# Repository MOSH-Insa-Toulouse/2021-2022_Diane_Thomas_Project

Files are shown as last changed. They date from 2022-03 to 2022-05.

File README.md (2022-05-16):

# 2021-2022_Diane_Thomas_Project
Protocol de réalisation de capteurs low-tech à base de graphite

## Sommaire
 
  - [Test circuit avec LT-Spice](#test-circuit-avec-lt-spice)
  - [Réalisation PCB KICAD](#réalisation-pcb-kicad)
  - [Réalisation PCB physique](#réalisation-pcb-physique)
  - [Code Arduino](#code-arduino)
  - [APK MIT AppInventor](#apk-mit-appinventor)
  - [Banc de test](#banc-de-test)
  - [Amélioration à apporter](#amélioration-à-apporter)
  - [Point d'amélioration](#point-damélioration)
  - [Auteurs](#auteurs)

### Test circuit avec LT-Spice

Circuit_suggéré

Nous avons commencé par réaliser le circuit trans-impédance ci-dessus sur LT-Spice afin de déterminer la fonction de chaque filtre sur le circuit et aussi déterminer l'atténuation globale d'un bruit en courant de 50 Hz et aussi l'atténuation globale d'un bruit en courant à la fréquence limite de repliement.

1.1. Etude des filtres

Pour chaque filtre nous avons mesuré la fréquence de coupure expérimentalement avec LT-Spise et ensuite nous avons fait le calcul théorique avec la formule *fc=1/2*pi*R*C. Nous avons obtenus des valeurs expérimentales et théoriques très proches pour chaque filtre.

- Visualisation mesure filtre *R1C1*
filtre 1 R1C1

Fréquence de coupure mesurée d'environ *16Hz*, ce filtre sert à filtrer le bruit de courant et aussi d'éviter les bruits de hautes fréquences causés par distorsion dans les étages d'entrée 

- Visualisation mesures filtre *R3C4*
filtre 2 R3C4

Fréquence de coupure d'environ 1.6Hz, c'est un filtre actif passe bas qui permet d'avoir le maximum d'efficacité en maintenant le  gain constant.

- Visualition filtre R6C2
filtre 3 R6C2

 Fréquence de coupure d'environ 1.6kHz, c'est le filtre de sortie qui permet d'adapter la fréquence du signal à la carte ADC arduino. Il empêche les fréquences élevées (bruit d'alimentation...) de passer dans l'ADC
 
 - La capacité C3 elle permet de filtrer le bruit d'alimentation.
 
 1.2. Etude de l'atténuation à la fréquence de coupure et à la fréquence de niquyst
 Gain global obtenu ~140dB
 - Atténuation à la fréquence de 50Hz
 gain 50Hz
 A 50Hz on mesure un gain ~100dB ce qui traduit une atténution de ~ 40dB
 
 - Atténuation à la fréquence de niquyst=7.5kH
 gain fnyquist
 A fniquyst on a un gain de 32.8dB, ce qui traduit une atténuation de ~ 100dB

## Réalisation PCB KICAD

Pour la réalisation de notre PCB nous avons utilisé le logiciel KICAD. Nous avons d'abord effectué le schématique en assignant à chaque composants (Bluetooth, oled, encodeur rotatoire) une empreinte et un symbole que nous avons réalisé, ensuite nous avons assigné à chaque composant un motif 3D pour la visualisation, et enfin nous avons effectué le routage de notre carte PCB

2.1. Schématique

Schématique

2.2. Symbole et Empreinte des composants

-Module bluetooth

Module_bluetooth

-Encodeur rotatoire

encodeur_rotatoire

-Oled

Oled

2.3 Carte PCB 

Carte_PCB

2.4 Carte PCB visu 3d

Visu3d

## Réalisation PCB physique
Nous avons imprimé notre circuit sur une carte d'epoxy recouverte de cuivre qui est elle-même couverte par une résine positive photosensible.
Notre circuit a d'abord été imprimé(avec une imprimante classique à l'encre) sur du papier plastique transparent, faisant office de masque lors de l'insolation. 
Les motifs ont été ensuite transferrés sur la carte par insolation aux UV et un passage au développeur pour dissoudre la résine insolée.
Ensuite nous passons la carte dans un bain de perclorure de fer pour dissoudre les parties métalliques qui ont été revélées lors de l'insolation. 
Après cette étape, nous rinçons notre carte à l'eau et la plongeons dans un bain d'acétone pour enlever la résine qui protégeait les autres parties du circuit. 
Enfin l'on rince encore à l'eau et voilà, notre carte est prête. 
On utilise un foret pour le perçage et enfin on soude les composants(résistances, capacités, amplificateur,..... ) sur la carte.

CartePCB_marche

## Code Arduino 
Dans notre code arduino, nous récuperons la valeur de la tension de notre capteur que nous convertissons en résistance. Nous affichons cette tension et cette  résistance sur l'oled et sur l'application que nous avons réalisée sur MIT AppIventor en envoyant la donnée de tension par le module Bluetooth. Une pression sur l'encodeur rotatoire permet de de changer l'affichage sur l'écran OLED, et de passer de l'affichage de la résistance à l'affichage de la tension (et inversement). 

Vous trouverez le code ici [Code arduino](https://github.com/MOSH-Insa-Toulouse/2021-2022_Diane_Thomas_Project/tree/main/Code_Biblioth%C3%A8que%20Arduino/code_capteur) .

## APK MIT AppInventor
Pour Installer l'application, il vous suffit de télécharger le fichier .apk sur votre téléphone et de l'installer.
Vous trouverez ce fichier dans ce dosssier [APK app inventor](https://github.com/MOSH-Insa-Toulouse/2021-2022_Diane_Thomas_Project/tree/main/APK%20app%20inventor).
L'application permet de lire les valeurs de résistance et de tension mesurées, et aussi de voir la courbe de mesure de la résistance.
Un bouton vous permet de vous connecter et vous déconnecter. Après la mesure il est possible de récuperer les valeurs de tension et de résistance mesurées dans un fichier txt qui s'enregistre automatiquement dans vos documents.

APK

## Banc de test

Nous avons effectué notre banc de test en utilisant des cylindres de différents diamètres(1, 1.5, 2, 2.5, 3, 3.5, 4 cm) fabriqués avec du papier recyclé. On met le capteur en tension, en le faisant épouser la forme des différents cylindre).
Les resultats peuvent être consulté ici [Datasheet et banc de test](https://github.com/MOSH-Insa-Toulouse/2021-2022_Diane_Thomas_Project/tree/main/Datasheet%20et%20banc%20de%20test) .

Cylindre_banc_test

## Amélioration à apporter
Notre banc de test présente certaines limites et peut être amélioré.
On a:

- La non répétabilité des mesures. En effet, les déformations appliquées peuvent varier entre chaque mesure: le banc de test ne permet pas d’appliquer une déformation identique. On pourrait envisager un banc de test fonctionnant avec un servomoteur par exemple (Ce système permet de générer des contraintes avec des angles bien précis et d'obtenir, de ce fait, une meilleure reproductibilité)

- Le dépôt de graphite sur le papier qui ne peut pas être maitrisé cela conduit une variation de mesure pour différents dépôts de même graphite.

-la déformation irréversible du capteur après un certains nombres de mesures.

#### Point d'amélioration

Afin de pouvoir lire une plus grande plage de résistance tout en ayant des mesures stables, il faudrait pouvoir changer le gain du circuit trans-impédance c'est à dire modifier la résistance R2 (voir schéma KiCad ). Cependant nous l'avons soudée sur le circuit PCB. Il faut donc à la place de la résistance R2 mettre un potentiomètre qui permet de varier  celle-ci.

## Auteurs
  
  - Bonkoungou Diane bonkoung@etud.insa-toulouse.fr
  - Bousquet Thomas tbousque@etud.insa-toulouse.fr

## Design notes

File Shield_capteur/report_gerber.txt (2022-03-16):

Plotted to 'C:\Users\diane\Desktop\GIT_Depot\MOSCH_project\2021-2022_Diane_Thomas_Project\Shiel_capteur\Fichier Gerber\LT1050-B_Cu.pdf'.
Info: Fini.

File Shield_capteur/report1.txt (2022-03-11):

Info: Processing symbol 'C1:Capacitor_THT:C_Disc_D10.0mm_W2.5mm_P5.00mm'.
Info: Processing symbol 'P7:Socket_Arduino_Uno:Arduino_1pin'.
Info: Processing symbol 'P8:Socket_Arduino_Uno:Arduino_1pin'.
Info: Processing symbol 'C2:Capacitor_THT:C_Disc_D10.0mm_W2.5mm_P5.00mm'.
Info: Processing symbol 'C3:Capacitor_THT:C_Disc_D10.0mm_W2.5mm_P5.00mm'.
Info: Processing symbol 'C4:Capacitor_THT:C_Rect_L9.0mm_W5.1mm_P7.50mm_MKT'.
Info: Processing symbol 'R1:Resistor_THT:R_Axial_DIN0207_L6.3mm_D2.5mm_P10.16mm_Horizontal'.
Info: Processing symbol 'R3:Resistor_THT:R_Axial_DIN0207_L6.3mm_D2.5mm_P10.16mm_Horizontal'.
Info: Processing symbol 'keyes_KY_1:Librarie_composant:Encodeur_rotatoire'.
Info: Processing symbol 'R2:Resistor_THT:R_Axial_DIN0207_L6.3mm_D2.5mm_P10.16mm_Horizontal'.
Info: Processing symbol 'P3:Socket_Arduino_Uno:Socket_Strip_Arduino_1x10'.
Info: Processing symbol 'U3:Librarie_composant:Module bluetooth'.
Info: Processing symbol 'R5:Resistor_THT:R_Axial_DIN0207_L6.3mm_D2.5mm_P10.16mm_Horizontal'.
Info: Processing symbol 'P5:Socket_Arduino_Uno:Arduino_1pin'.
Info: Processing symbol 'P4:Socket_Arduino_Uno:Socket_Strip_Arduino_1x08'.
Info: Processing symbol 'P6:Socket_Arduino_Uno:Arduino_1pin'.
Info: Processing symbol 'P1:Socket_Arduino_Uno:Socket_Strip_Arduino_1x08'.
Info: Processing symbol 'P2:Socket_Arduino_Uno:Socket_Strip_Arduino_1x06'.
Info: Processing symbol 'R6:Resistor_THT:R_Axial_DIN0207_L6.3mm_D2.5mm_P10.16mm_Horizontal'.
Info: Processing symbol 'U1:Librarie_composant:DIP-8_296_ELL'.
Info: Processing symbol 'U2:Librarie_composant:Capteur_graphite'.
Info: Processing symbol 'U4:Librarie_composant:OLED'.
Add net CLK.
Reconnected keyes_KY_1 pin 1 from unconnected-(keyes_KY_1-Pad1) to CLK.
Reconnected keyes_KY_1 pin 2 from unconnected-(keyes_KY_1-Pad2) to DT.
Add net SW.
Reconnected keyes_KY_1 pin 3 from unconnected-(keyes_KY_1-Pad3) to SW.
Reconnected keyes_KY_1 pin 4 from unconnected-(keyes_KY_1-Pad4) to +5V.
Reconnected P2 pin 1 from /A0 to ADC.
Add net SDA.
Reconnected P2 pin 5 from /A4(SDA) to SDA.
Add net SCL.
Reconnected P2 pin 6 from /A5(SCL) to SCL.
Reconnected P3 pin 7 from /11(**/MOSI) to SW.
Reconnected P3 pin 8 from /10(**/SS) to DT.
Add net /7.
Reconnected P4 pin 1 from +5V to /7.
Reconnected P4 pin 6 from 2 to CLK.
Add net TXD.
Reconnected P4 pin 7 from /1(Tx) to TXD.
Add net RXD.
Reconnected P4 pin 8 from /0(Rx) to RXD.
Reconnected R1 pin 1 from 3 to IN+.
Reconnected R2 pin 2 from 2 to IN-.
Reconnected R3 pin 1 from 2 to IN-.
Add net DT.
Reconnected R5 pin 1 from /Isens to capteur.
Reconnected R5 pin 2 from 3 to IN+.
Add net IN+.
Reconnected C1 pin 1 from 3 to IN+.
Reconnected U1 pin 2 from 2 to IN-.
Reconnected U1 pin 3 from 3 to IN+.
Add net IN-.
Updated U2 symbol association from /3deabf90-4200-44e5-96f0-6dbdb285e2f9 to /9f589ed3-a6b9-4e31-a518-6362035b54b5.
Connected U2 pin 1 to capteur.
Connected U2 pin 2 to +5V.
Add net capteur.
Added U3 (footprint 'Librarie_composant:Module bluetooth').
Changed HC-05 reference designator to U3.
Changed U3 value from Module bluetooth to Module_bluetooth.
Updated U3 symbol association from  to /ebefff93-806b-4ffd-bb33-46db61c698c7.
Updated U3 properties.
Add net unconnected-(U3-Pad1).
Connected U3 pin 1 to unconnected-(U3-Pad1).
Connected U3 pin 2 to +5V.
Connected U3 pin 3 to GND.
Connected U3 pin 4 to TXD.
Connected U3 pin 5 to RXD.
Add net unconnected-(U3-Pad6).
Connected U3 pin 6 to unconnected-(U3-Pad6).
Reconnected C4 pin 1 from 2 to IN-.
Added U4 (footprint 'Librarie_composant:OLED').
Changed REF** reference designator to U4.
Updated U4 symbol association from  to /e9f552ce-c538-4f28-af5f-c07fb8584760.
Updated U4 properties.
Connected U4 pin 1 to +5V.
Connected U4 pin 2 to GND.
Connected U4 pin 3 to SCL.
Connected U4 pin 4 to SDA.
Removed unused net /0(Rx).
Removed unused net /1(Tx).
Removed unused net /10(**{slash}SS).
Removed unused net /11(**{slash}MOSI).
Removed unused net /A0.
Removed unused net /Isens.
Removed unused net 2.
Removed unused net 3.
Removed unused net unconnected-(keyes_KY_1-Pad1).
Removed unused net unconnected-(keyes_KY_1-Pad2).
Removed unused net unconnected-(keyes_KY_1-Pad3).
Removed unused net unconnected-(keyes_KY_1-Pad4).

Info: Total warnings: 0, errors: 0.

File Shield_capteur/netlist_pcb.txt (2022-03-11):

Info: Reading netlist file 'C:\Users\diane\Desktop\Shield arduino\PCB_EXAM\LT1050\netlist.net'.

Info: Using reference designators to match symbols and footprints.

Info: Processing symbol 'P3:Socket_Arduino_Uno:Socket_Strip_Arduino_1x10'.
Info: Processing symbol 'P1:Socket_Arduino_Uno:Socket_Strip_Arduino_1x08'.
Info: Processing symbol 'P4:Socket_Arduino_Uno:Socket_Strip_Arduino_1x08'.
Info: Processing symbol 'P2:Socket_Arduino_Uno:Socket_Strip_Arduino_1x06'.
Info: Processing symbol 'P5:Socket_Arduino_Uno:Arduino_1pin'.
Info: Processing symbol 'P6:Socket_Arduino_Uno:Arduino_1pin'.
Info: Processing symbol 'P7:Socket_Arduino_Uno:Arduino_1pin'.
Info: Processing symbol 'P8:Socket_Arduino_Uno:Arduino_1pin'.
Info: Processing symbol 'U1:Librarie_composant:DIP-8_296_ELL'.

Info: Total warnings: 0, errors: 0.

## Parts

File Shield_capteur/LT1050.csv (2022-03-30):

Source: | C:\Users\diane\Desktop\GIT_Depot\MOSCH_project\2021-2022_Diane_Thomas_Project\Shiel_capteur\LT1050.kicad_sch
Date: | 16/03/2022 17:25:07
Tool: | Eeschema (6.0.1)
Generator: | C:\Program Files\KiCad\6.0\bin\scripting\plugins/bom_csv_grouped_by_value_with_fp.py
Component Count: | 22
Ref | Qnty | Value | Cmp name | Footprint | Description | Vendor
C1, C2, C3, | 3 | 100n | C | Capacitor_THT:C_Disc_D3.4mm_W2.1mm_P2.50mm | Unpolarized capacitor
C4, | 1 | 1u | C | Capacitor_THT:C_Rect_L9.0mm_W5.1mm_P7.50mm_MKT | Unpolarized capacitor
keyes_KY_1, | 1 | Encodeur_rotatoire | Encodeur_rotatoire | Librarie_composant:Encodeur_rotatoire
P1, | 1 | Power | Conn_01x08 | Socket_Arduino_Uno:Socket_Strip_Arduino_1x08 | Generic connector, single row, 01x08, script generated (kicad-library-utils/schlib/autogen/connector/)
P2, | 1 | Analog | Conn_01x06 | Socket_Arduino_Uno:Socket_Strip_Arduino_1x06 | Generic connector, single row, 01x06, script generated (kicad-library-utils/schlib/autogen/connector/)
P3, | 1 | Digital | Conn_01x10 | Socket_Arduino_Uno:Socket_Strip_Arduino_1x10 | Generic connector, single row, 01x10, script generated (kicad-library-utils/schlib/autogen/connector/)
P4, | 1 | Digital | Conn_01x08 | Socket_Arduino_Uno:Socket_Strip_Arduino_1x08 | Generic connector, single row, 01x08, script generated (kicad-library-utils/schlib/autogen/connector/)
P5, P6, P7, P8, | 4 | CONN_01X01 | Conn_01x01 | Socket_Arduino_Uno:Arduino_1pin | Generic connector, single row, 01x01, script generated (kicad-library-utils/schlib/autogen/connector/)
R1, R3, | 2 | 100k | R | Resistor_THT:R_Axial_DIN0207_L6.3mm_D2.5mm_P10.16mm_Horizontal | Resistor
R2, R6, | 2 | 1k | R | Resistor_THT:R_Axial_DIN0207_L6.3mm_D2.5mm_P10.16mm_Horizontal | Resistor
R5, | 1 | 10k | R | Resistor_THT:R_Axial_DIN0207_L6.3mm_D2.5mm_P10.16mm_Horizontal | Resistor
U0, | 1 | Capteur_graphite | Capteur_graphite_1 | Librarie_composant:Capteur_graphite
U1, | 1 | LT1050 | LT1050 | Librarie_composant:DIP-8_296_ELL
U2, | 1 | Module_bluetooth | Module_bluetooth_1 | Librarie_composant:Module bluetooth
U3, | 1 | OLED | OLED | Librarie_composant:OLED

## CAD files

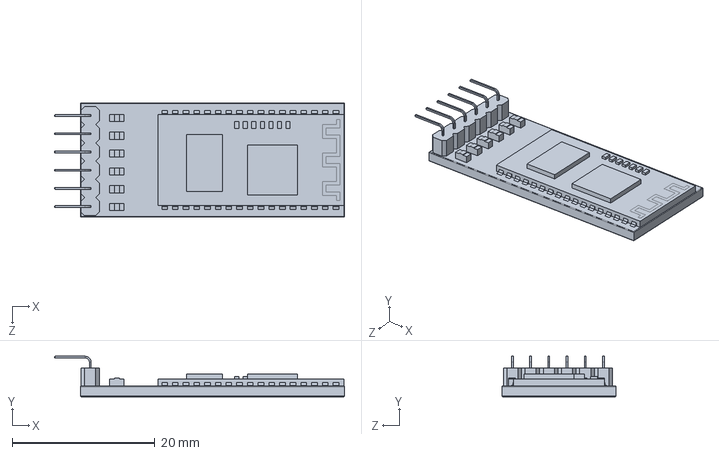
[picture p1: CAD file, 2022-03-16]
Shield_capteur/Motif 3d/HC05.STEP
40.6 x 5.67 x 16.0 mm

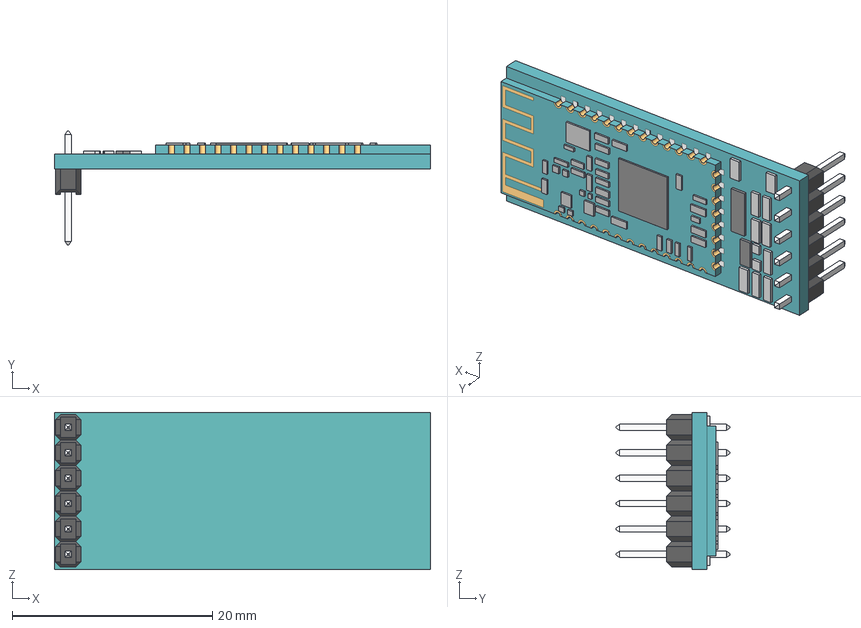
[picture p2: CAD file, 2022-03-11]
Shield_capteur/Motif 3d/HC-SERIES.STEP
37.6 x 11.4 x 15.7 mm
Pin Header 6 x 1 TH 2.54mm Pitch x 12

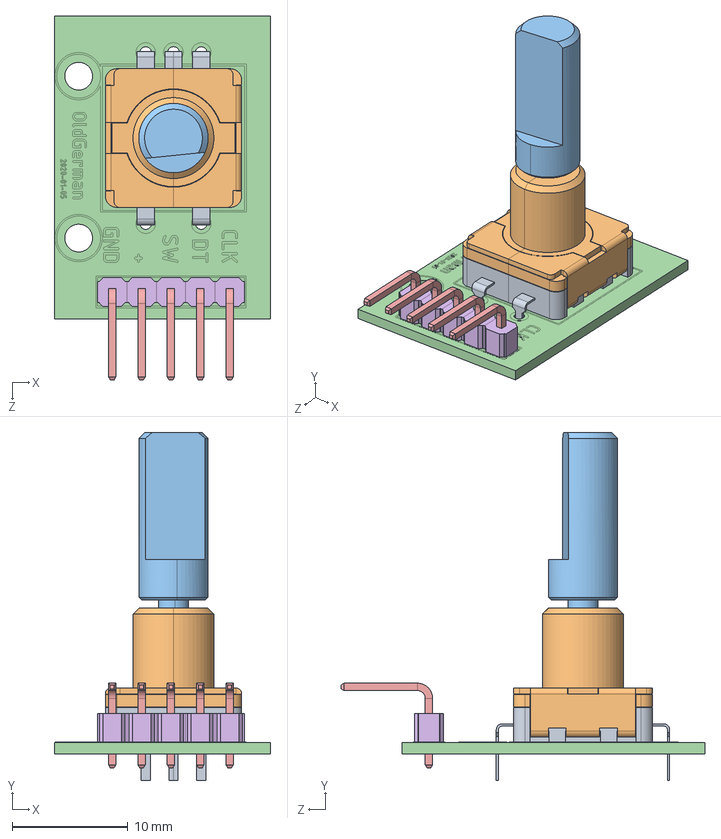
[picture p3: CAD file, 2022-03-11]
Shield_capteur/Motif 3d/KY-040 Rotary Encoder.STEP
18.7 x 30.1 x 31.5 mm
Rotary Encoder
D-handle
pcb
2.54 5PIN 90

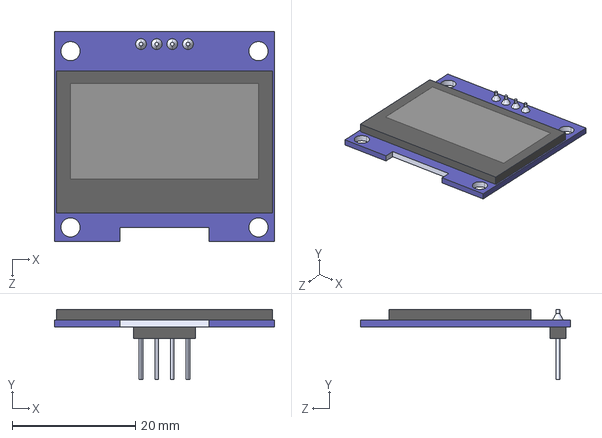
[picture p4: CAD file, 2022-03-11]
Shield_capteur/Motif 3d/Display_OLED_SSD1306_1.3inch.STEP
35.7 x 11.4 x 34.0 mm

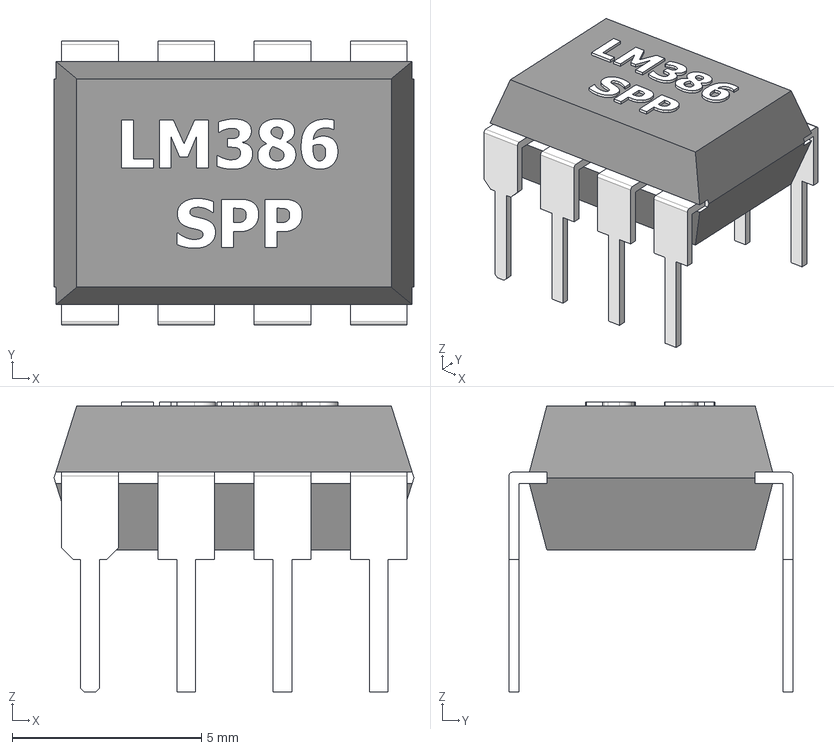
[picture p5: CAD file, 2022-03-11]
Shield_capteur/Motif 3d/LM386 SPP.stp
9.50 x 7.50 x 7.65 mm

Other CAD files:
Shield_capteur/Motif 3d/HC_05 Blue Tooth Module.ipt

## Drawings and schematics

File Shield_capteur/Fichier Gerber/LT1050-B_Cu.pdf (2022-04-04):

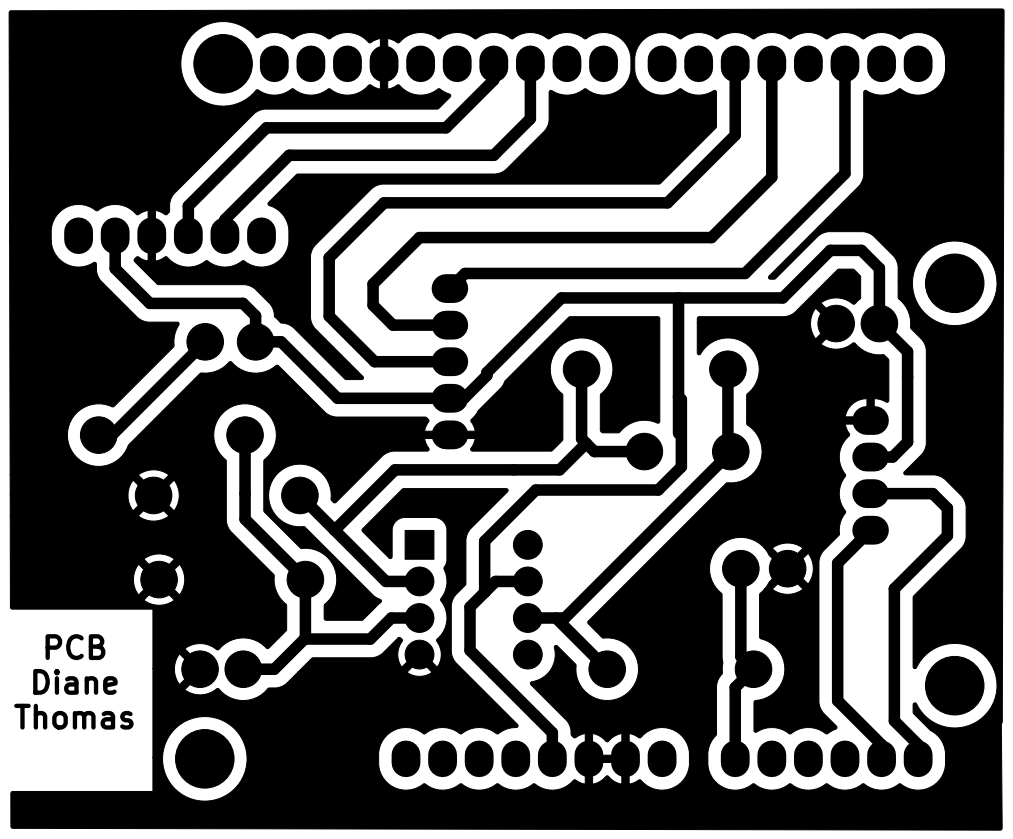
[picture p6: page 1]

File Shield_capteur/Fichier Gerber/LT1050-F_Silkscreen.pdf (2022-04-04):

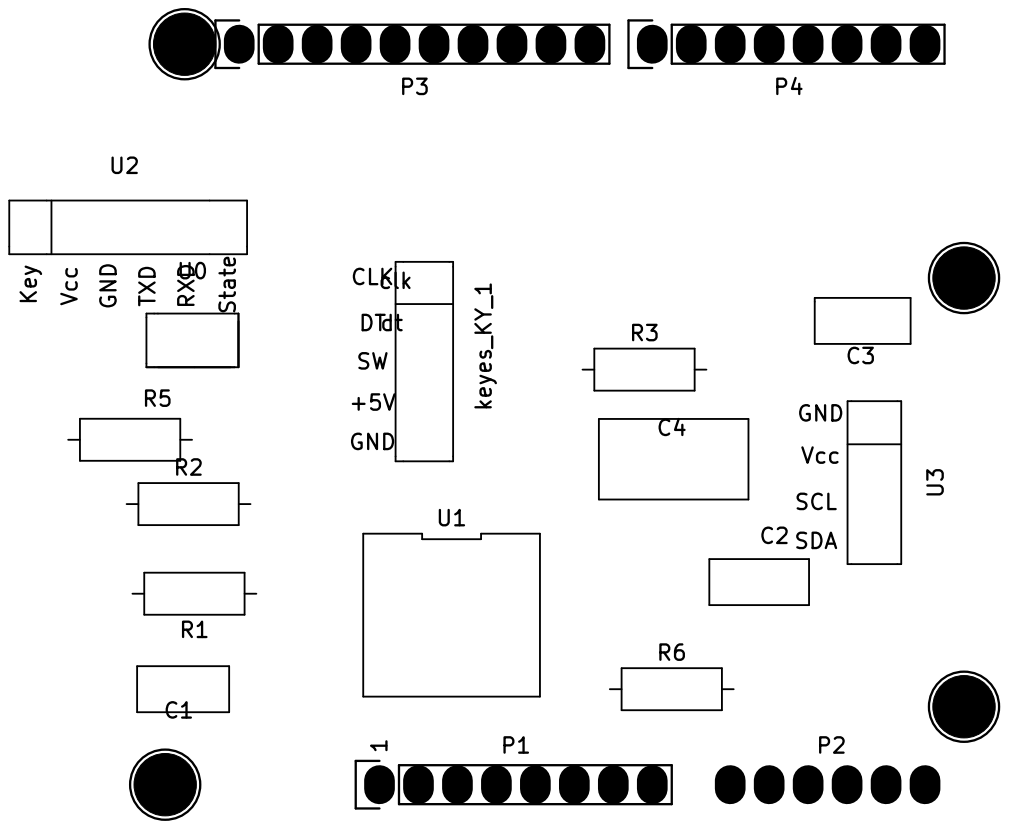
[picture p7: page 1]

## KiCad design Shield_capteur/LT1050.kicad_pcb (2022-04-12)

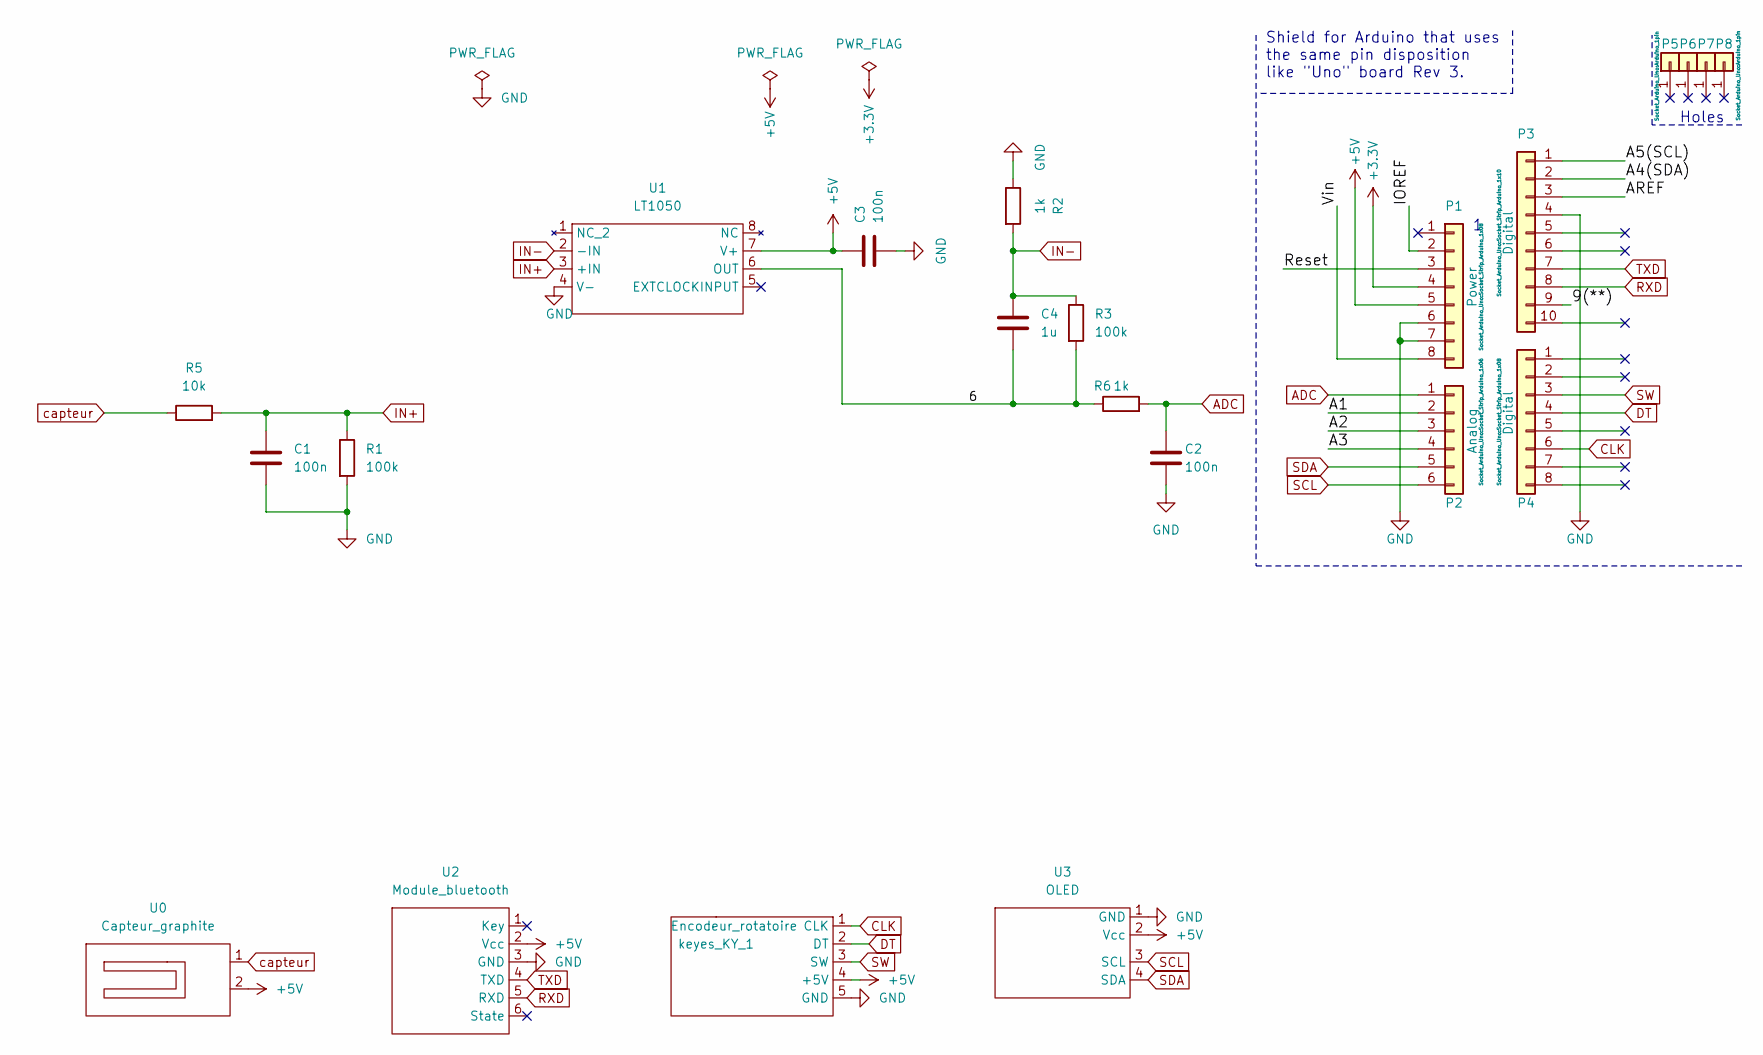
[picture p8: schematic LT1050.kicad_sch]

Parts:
C1, C2, C3: 100n; C_Disc_D3.4mm_W2.1mm_P2.50mm
C4: 1u; C_Rect_L7.5mm_W6.5mm_P5.00mm
P1: Power; Socket_Strip_Arduino_1x08
P2: Analog; Socket_Strip_Arduino_1x06
P3: Digital; Socket_Strip_Arduino_1x10
P4: Digital; Socket_Strip_Arduino_1x08
P5, P6, P7, P8: CONN_01X01; Arduino_1pin
R1, R3: 100k; R_Axial_DIN0207_L6.3mm_D2.5mm_P10.16mm_Horizontal
R2, R6: 1k; R_Axial_DIN0207_L6.3mm_D2.5mm_P10.16mm_Horizontal
R5: 10k; R_Axial_DIN0207_L6.3mm_D2.5mm_P10.16mm_Horizontal
U0: Capteur_graphite
U1: LT1050; DIP-8_296_ELL
U2: Module_bluetooth; Module bluetooth
U3: OLED
keyes_KY_1: Encodeur_rotatoire

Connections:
+3V3: P1.4
+5V: C3.1, P1.5, U0.2, U1.7 (V+), U2.2 (Vcc), U3.2 (Vcc), keyes_KY_1.4 (+5V)
/6: C4.2, R3.2, R6.1, U1.6 (OUT)
/9(**): P3.9
/A1: P2.2
/A2: P2.3
/A3: P2.4
/A4(SDA): P3.2
/A5(SCL): P3.1
/AREF: P3.3
/IOREF: P1.2
/Reset: P1.3
/Vin: P1.8
ADC: C2.1, P2.1, R6.2
CLK: P4.6, keyes_KY_1.1 (CLK)
DT: P4.4, keyes_KY_1.2 (DT)
GND: C1.2, C2.2, C3.2, P1.6, P1.7, P3.4, R1.2, R2.1, U1.4 (V-), U2.3 (GND), U3.1 (GND), keyes_KY_1.5 (GND)
IN+: C1.1, R1.1, R5.2, U1.3 (+IN)
IN-: C4.1, R2.2, R3.1, U1.2 (-IN)
RXD: P3.8, U2.5 (RXD)
SCL: P2.6, U3.3 (SCL)
SDA: P2.5, U3.4 (SDA)
SW: P4.3, keyes_KY_1.3 (SW)
TXD: P3.7, U2.4 (TXD)
capteur: R5.1, U0.1

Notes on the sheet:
Holes
Shield for Arduino that uses the same pin disposition like "Uno" board Rev 3.

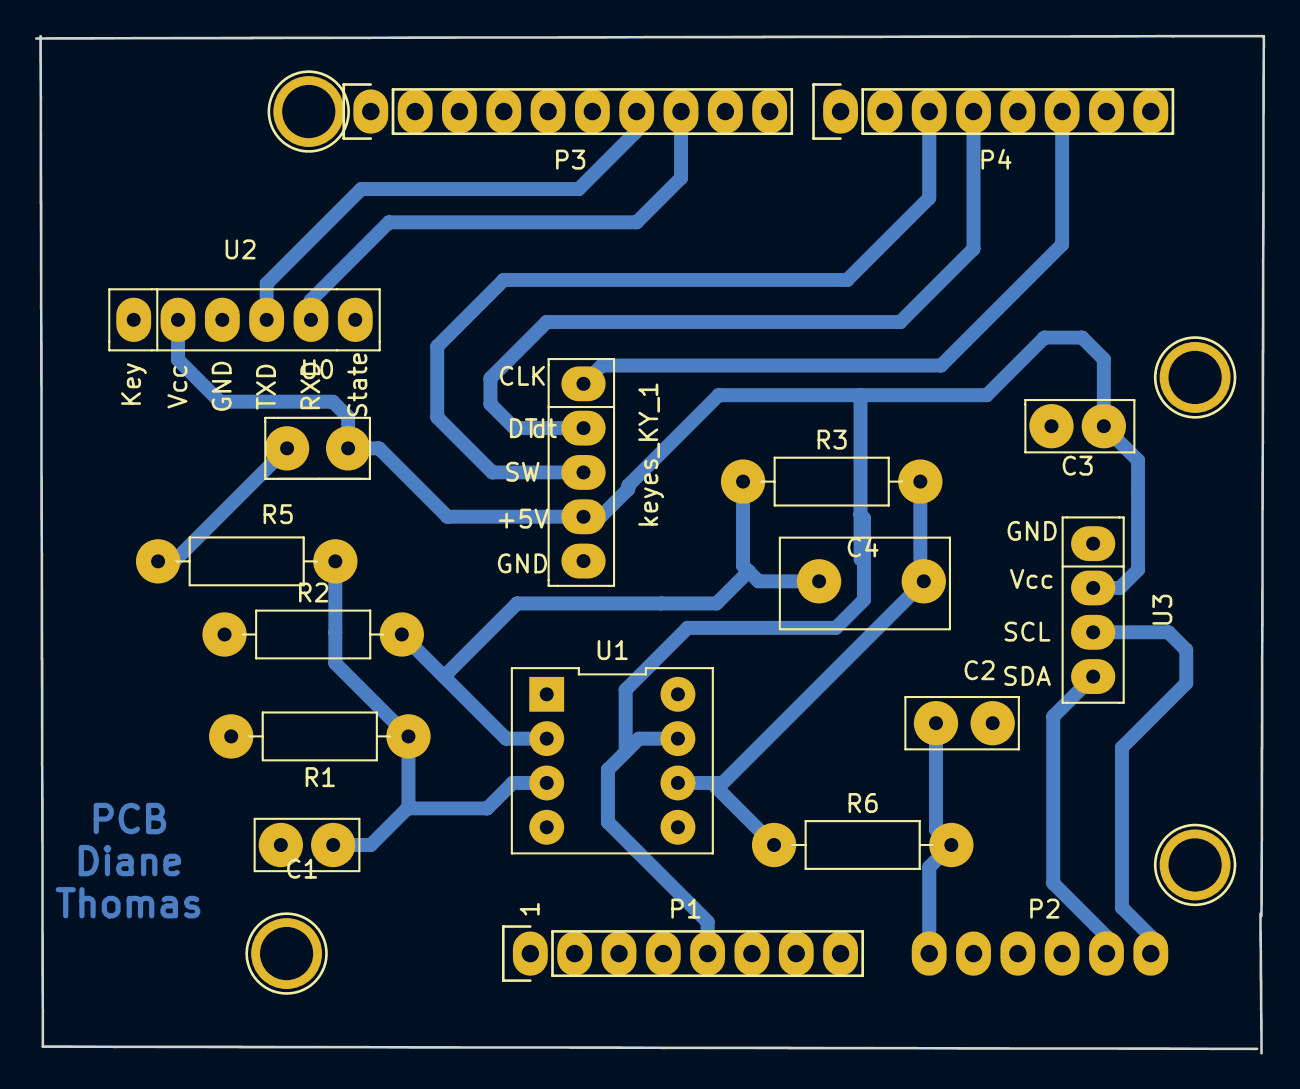
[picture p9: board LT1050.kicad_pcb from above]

Board: 2 copper layers, 70.4 x 58.3 mm, 22 parts (0 on the bottom side), 14 nets.

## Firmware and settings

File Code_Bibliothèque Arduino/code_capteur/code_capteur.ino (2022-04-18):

#include <Adafruit_SSD1306.h> //librairie affichage oled
#include <splash.h>
#include <Adafruit_GFX.h>
#include <Adafruit_GrayOLED.h>
#include <Adafruit_SPITFT.h>
#include <Adafruit_SPITFT_Macros.h>
#include <gfxfont.h>
#include <SoftwareSerial.h> //librairie communication serie bluetooth
#include <SPI.h> //librairie communication en mode SPI
#include <Wire.h>
#define nbrePixelsLargeur 128
#define nbrePixelsHauteur 64
#define adresseI2CecranOLED 0x3C


 

#define baudrate 9600

//HC-05 variables Bluetooth
#define rxPin 11
#define txPin 10


SoftwareSerial mySerial(rxPin, txPin);


//compteur millisecondes
unsigned long previousMillis = 0;
const long interval = 2000;

//Variables Capteur - sortie ADC (lecture tension)
#define analog_port 0

//Variables Écran
#define SCREEN_ADDRESS 0x3C
Adafruit_SSD1306 ecranOLED(nbrePixelsLargeur, nbrePixelsHauteur, &Wire,-1); //-1 car pas de pin reset quand reset disponible on le defini en utilisant un port digital

// Variables Encodeur Rotatoire
#define clkPin 2
#define dtPin 4
#define swPin 5
boolean LeftRight;
int rotation;
int value;

//Déclaration variable recupération tension et resistance mesurée
float Voltage1;
float Vcc=5. ;
float R1=100000 ;
float R2=1000.;
float R3=100000.;
float R5=10000.;

float Resistance;
int menu = 0;
//encodeur
bool clkState = LOW;
bool clkLast = HIGH;
bool swState = HIGH;
bool swLast = HIGH;
int rotVal = 0;


//SoftwareSerial mySerial(rxPin, INPUT);//


//DEFINITION FONCTION


//Retourne le nombre de fois ou l'on a appuyer sur l'encodeur
int readSw() { /* function readRotary */

  //gestion bouton
  swState = digitalRead(swPin);
  if (swState == LOW && swLast == HIGH) {
    menu++;
    delay(100);//debounce
  }
  swLast = swState;
  return menu;
}

//Affiche ecran oled

void Affichage_Menu() {
  ecranOLED.clearDisplay();
  ecranOLED.setTextSize(2);
  ecranOLED.setTextColor(WHITE);

  ecranOLED.setCursor(0, 0);
  ecranOLED.println(F("Capteur"));
  ecranOLED.setTextSize(1);
  ecranOLED.setCursor(0, 17);
  ecranOLED.println("Appuyez pour defiller");
  ecranOLED.display();
}

//Affiche la tension

void Affichage_Tension (double u)
{

  ecranOLED.clearDisplay();
  ecranOLED.setTextSize(2);
  ecranOLED.setTextColor(WHITE);

  ecranOLED.setCursor(30, 0);
  ecranOLED.println(F("Tension"));
  ecranOLED.setCursor(40, 17);
  ecranOLED.println(u);
  ecranOLED.setCursor(90, 17);
  ecranOLED.println(F("V"));
  ecranOLED.display();
}

//Affiche la resistance

void Affichage_Resistance (double r)
{
  ecranOLED.clearDisplay();
  ecranOLED.setTextSize(2);
  ecranOLED.setTextColor(WHITE);

  ecranOLED.setCursor(5, 0);
  ecranOLED.println(F("Resistance"));
  ecranOLED.setCursor(0, 17);
  ecranOLED.println(r, 1);
  ecranOLED.setCursor(65, 17);
  ecranOLED.println(F("MOhms"));
  ecranOLED.display();
}

 

void setup()
{
  //Mode des pin de l'encodeur rotatoire
  pinMode(clkPin, INPUT);
  pinMode(dtPin, INPUT);
  pinMode(swPin, INPUT_PULLUP);

  //Ouverture des ports serie pour la communication bluetooth
  pinMode(rxPin, INPUT);
  pinMode(txPin, OUTPUT);
  Serial.begin(baudrate);

  //bluetooth
  pinMode(rxPin,INPUT);
  pinMode(txPin,OUTPUT);

  mySerial.begin(9600);


  //Affichage oled init
  ecranOLED.begin(SSD1306_SWITCHCAPVCC, SCREEN_ADDRESS);
  ecranOLED.clearDisplay();
  Affichage_Menu();
}

 

void loop()
{

 
//Lis les valeurs de tension, met l'écran à jour, envoie les valeurs en bluetooth ... à chaque intervalle de temps
unsigned long currentMillis =millis();
if (currentMillis - previousMillis >= interval) {

  previousMillis = currentMillis;

  Voltage1 = analogRead(analog_port) *5. / 1023.; //Tension sur 5V et 10bits
  Resistance = (1 + 100) * 100000 * (5 / Voltage1) - 100000 - 10000;//Calcule de la résistance
  Serial.print(Voltage1);//envoie de la valeur au moniteur serie
  Serial.println(" ");//séparateur entre la valeur de tension et de résistance
  
//envoi données bluetooth

  mySerial.print(Voltage1);
  mySerial.println(" ");
}
 //met à jour valeur de l'encodeur rotatoire en continu, sans tenir compte de l'intervalle de temps
  value = digitalRead(clkPin);
  if (value != rotation){ // we use the DT pin to find out which way we turning.
    if (digitalRead(dtPin) != value) { // Clockwise
      rotVal++;
      LeftRight = true;
      if (rotVal>=40){
       rotVal = rotVal%40;
      }
      if (rotVal<0){
        rotVal = 40+rotVal;
      }
    } else { //Counterclockwise
      LeftRight = false;
      rotVal--;
      if (rotVal>=40){
        rotVal = rotVal%40;
      }
      if (rotVal<0){
        rotVal = 40+rotVal;
      }
    } 

  rotation = value;
}
   if (readSw()%2==0) {
    Affichage_Resistance (Resistance/1000000); //affichage de la résistance en Mohm//
  }
  if (readSw()%2!=0) {
    Affichage_Tension (Voltage1);
  }
}

 

 

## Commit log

2022-03-08 ajout kicad
2022-03-08 suppression kicad
2022-03-11 ajout de fichier kicad
    [Display_OLED_SSD1306_1.3inch.STEP, HC-SERIES.STEP, HC_05 Blue Tooth Module.ipt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]
2022-03-11 mis à jour kicad
2022-03-15 correction routage
    [LT1050.kicad_pcb, LT1050.kicad_sch]
2022-03-16 ajout tracerkicad
    [HC05.STEP, LM386 SPP.stp, LT1050.kicad_pcb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]
2022-03-16 mise à jour pcb
    [LM386 SPP.stp, LT1050.kicad_pcb, LT1050.kicad_sch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]
2022-03-30 correction cathy
    [LT1050.csv, LT1050.kicad_pcb, LT1050.kicad_sch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]
2022-03-31 ajout ltspice
    [LT1050.kicad_pcb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]
2022-03-31 mise à jour correction kicad Cathy
    [LT1050.kicad_pcb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]
2022-04-01 kicad plan de masse
    [LT1050-NPTH.drl, LT1050-PTH.drl]
2022-04-04 ajout fichier Fsilcreen
    [LT1050-NPTH.drl, LT1050-PTH.drl]
2022-04-12 fin kicad et ajout ltspice
    [LT1050.kicad_pcb]
2022-04-15 nom kicad_change
    [Display_OLED_SSD1306_1.3inch.STEP, HC-SERIES.STEP, HC05.STEP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]
2022-04-15 ajout code arduino
2022-04-18 modification code arduino
2022-04-18 ajout pcb
